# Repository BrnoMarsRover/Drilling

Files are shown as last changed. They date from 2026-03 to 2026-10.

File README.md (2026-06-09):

# Drilling
Repo for Deep Sampling Sub-Task
Release 2025 was mostly a success and allowed us to identify its shortcomings.
Currently working on an overhauled design for ERC 2026.

## Authors

- **Filip Slima** *(Leader)*  
  Responsible for mechanical construction, linear motion system.

- **Vilem Strachon**  
  Responsible for the weighing and storing.

- **Ondrej Stafa**  
  Responsible for DC motor control.

## ESP software structure
```mermaid
graph TD;
    Main-->RoverComm;
    Main-->DeepSampler;
      DeepSampler-->DrillController;
        DrillController-->LinearAxis;
          LinearAxis-->Stepper1;
          LinearAxis-->Encoder1;
          LinearAxis-->LimitSwitch;
          LinearAxis-->CurrentSensor;
        DrillController-->SpiralMotor;
      	DrillController-->HeightSensor;
      DeepSampler-->DeepSampleHolder;
        DeepSampleHolder-->ADC1
        DeepSampleHolder-->StoragePositioner
          StoragePositioner-->Stepper2;
          StoragePositioner-->Encoder2;
  Main-->SurfaceSampleHolder;
    SurfaceSampleHolder-->ADC2
    SurfaceSampleHolder-->Servo1;
    SurfaceSampleHolder-->Servo2;
```

## Communication protocol
[Here](communicationProtocol.md)

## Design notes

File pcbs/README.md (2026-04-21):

# Součástky k nakoupení

- P-MOSFET na MainBoard 2, url: https://cz.mouser.com/ProductDetail/onsemi/FDN338P?qs=HK%252BeIG1iaag%252B6528k3ktAg%3D%3D\&srsltid=AfmBOopaRxGhuw91gWSMGtCGucpT9BQNKklBUyEe4Xwb5UvMYGCLGTto
- ADC rezervní, url: https://cz.mouser.com/ProductDetail/Texas-Instruments/ADS122C04IPWR?qs=7EBvPakHacWatwmmdfjwqQ%3D%3D

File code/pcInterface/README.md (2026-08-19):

# Drilling HMI

A desktop application for controlling and monitoring the drilling device.

It supports two connection modes, switchable in the app:

- **USB Serial** — direct connection to the ESP32 over UART. Used during
  standalone bench testing.
- **UDP (localhost)** — used once the drill is mounted on the rover. This
  app runs alongside the main rover communication app on the same laptop.
  Framed drill messages are sent over a localhost UDP socket to the main
  app, which is responsible for actually getting them to/from the drill
  over the rover link. Responses come back the same way.

## Requirements

- Python 3.8 or newer — download from https://www.python.org/downloads/
  - During installation, tick **"Add Python to PATH"** on the first screen
- For USB Serial mode: the ESP32 connected via USB (USB-to-serial adapter or direct USB)
- For UDP mode: the main rover communication app running on the same machine

## Installation

1. Open CMD and navigate to this folder:
   ```
   cd ...\Drilling\code\pcInterface
   ```

2. Install dependencies:
   ```
   pip install -r requirements.txt
   ```

## Running the application

```
python main.py
```

A window will open with a **Connection** bar at the top.

### USB Serial mode

Select **USB Serial**, choose the correct COM port from the dropdown, and
click **Connect**.

To find the correct COM port: open Device Manager → Ports (COM & LPT) →
look for your USB serial device.

### UDP (localhost) mode

Select **UDP (localhost)** and set two ports:

- **Listen port** — the port this app listens on. The main rover comms
  app must send the drill's responses to `127.0.0.1` on this port.
- **Send port** — the port this app sends to. The main rover comms app
  must be listening on `127.0.0.1` on this port.

These two ports must be different from each other, and must match
whatever the main app is configured to use on its side. Click **Connect**
to open the socket.

Note: UDP mode expects the main rover communication app to already be
running and listening — this app doesn't start or manage it.

The mode switch and its fields lock while connected; disconnect first to
change modes.

## Project structure

```
drilling-hmi/
├── main.py            # Entry point — run this
├── protocol.py        # Message building and parsing (checksum, framing)
├── comm_worker.py      # Background thread handling USB serial and UDP communication
├── gui.py              # All GUI windows and widgets
├── requirements.txt    # Python dependencies
└── README.md            # This file
```

## Notes

- Baud rate is fixed at 38400 as per the protocol spec (USB Serial mode only)
- The application will not send commands if not connected
- The STATE command is sent automatically every 500 ms when connected, regardless of mode
- `serial_worker.py` from earlier versions has been replaced by `comm_worker.py` — delete the old file if it's still present in this folder

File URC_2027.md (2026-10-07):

Feetech STS3215 servo pro pohon závitové tyče nebo nema 14 - potřeba enkoderu\
závitová tyč o měnším průměru\
Cubemars ak45:10 pořád na vrtání\
pořešit jeslit nejde brát 24 nebo 12 pro hlavní motor z roveru - ušetřit váhu měniče

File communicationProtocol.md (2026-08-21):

# Protocol for communication between the drill's microcontroller and rover's master computer

All messages are sent via UART with 38400 baud rate.\
All multi-byte variables are to be sent and received as big-endian - most significant byte is transmitted first.

1. The rover initiates communication by sending a message in the specified format. The payload of the message consists of a code of the function to be executed by the drill. The code is of type uint8. In some cases, the code must be followed by an argument. This is usually a numeric value, for example the desired depth to be drilled.

2. If the drill is able to start performing the function, it sends the function code back. If it is unable to perform the function, it sends back a zero. If further answer is expected (for example the weight of a sample), the function code is followed by the requested value.

## Message format
|Byte number  |Content |
|- |-|
|1 |0x02 |
|2 |Payload length  |
|3...n-2 |Payload  |
|n-1 |Checksum |
|n |0x03 |

The chekcsum algorithm is "Sum complement". See: https://en.wikipedia.org/wiki/Checksum#Sum_complement
The checksum is computed only from the payload.

## Communication program
A program has been developed for communicating with the drill according to this protocol. The program supports two modes of communication
1. The drill can be connected directly to a computer running the program via USB. This is simpler and meant for testing purposes when the drill is not mounted on the rover.
2. When the drill is mounted and connected to the rover, direct USB communication with a PC is not possible. A broader, main program exists for wireless communication with the rover. Our drill communication program then runs on the same computer as the main program. These two programs communicate via UDP localhost. The main program and the rover's computer then act as middlemen between this app and the drill itself. The drill program should send messages to port 5610 and can receive the drill's responses on port 5611.

## Example 1
Rover: 0x02 (start) -> 0x01 (length 1) -> 0x01 (message - reset) -> 0x?? (checksum) -> 0x03 (end)\
Drill: 0x02 (start) -> 0x01 (length 1) -> 0x01 (message - request to reset received. Resetting.) -> 0x?? (checksum) -> 0x03 (end) 

## Example 2
Rover: 0x02 (start) -> 0x01 (length 1) -> 0x42 (GET WEIGHT DEEP) -> 0x?? (checksum) -> 0x03 (end)\
Drill: 0x02 (start) -> 0x01 (length 5) -> 0x42 (Weight request received. Weight follows.) -> 4 bytes-float -> 0x?? (checksum) -> 0x03 (end)

## Function list
| Name and description | Message from rover | Function argument from rover | Response data from drill |
|- |- |- |- |
| RESTART - Restarts the microcontroller. Retracts the deep sample box. Returns the vertical drive to its uppermost position. Also calibrates the vertical position value. | 0x01 | None | None |
| STATE - Requests the state of the drilling mechanism | 0x02 | None | Response is in table below |
| CALIBRATE CARRIAGE DEPTH - Moves the carriage up, until it hits the top limit switch. Sets depth = 0 at that position. | 0x03 | None | None |
| START DEVICE CHECK - Checks whether peripheral devices are connected and responding. | 0x04 | None | None |
| GET DEVICE STATUS - Requests the result of the START DEVICE CHECK | 0x05 | None | uint16 (String of bits. Each bit corresponds to one peripheral device. 1 = OK, 0 = not OK. Order of devices in table below) |
| DRILL SPEED - sets the speed of the drill/spiral | 0x20 | int16 [RPM] | None |
| VERTICAL SPEED - sets the speed of the vertical drive | 0x21 | int8 [0,1 mm/s]<br>e.g.&nbsp;100 = 10mm/s | None |
| STORAGE POSITION - sets the position of the deep sample storage box | 0x22 | uint8 [position] | None |
| MEASURE HEIGHT ABOVE GROUND - requests height measurement. | 0x23 | None | None |
| GET HEIGHT ABOVE GROUND - requests the value of the last height measurement. | 0x24 | None | uint16 [mm] |
| WEIGH DEEP - Start weighing the deep sample. | 0x40 | None | None |
| WEIGH SURFACE - Start weighing the surface sample. | 0x41 | None | None |
| GET WEIGHT DEEP - Requests the result of WEIGH DEEP. | 0x42 | None | float [grams], uint32 [raw ADC value] |
| GET WEIGHT SURFACE - Requests the result of WEIGH SURFACE. | 0x43 | None | float [grams], uint32 [raw ADC value] |
| CALIBRATE 0 DEEP - Starts the calibration procedure. Calibrates the ADC value for empty storage. Needs to be followed by CALIBRATE X DEEP for successful calibration. | 0x44 | None | None |
| CALIBRATE X DEEP - Calibrates the ADC value for X grams in storage. Finishes calibration and saves data to nonvolatile flash memory. | 0x45 | Weight of the object put into storage -  float [grams] | None |
| CALIBRATE 0 SURFACE - Same as above, but for surface sample. | 0x46 | None | None |
| CALIBRATE X SURFACE - Same as above, but for surface sample. | 0x47 | Weight of the object put into storage -  float [grams] | None |
| ROCK OPEN - opens the rock sample box | 0x50 | None | None |
| ROCK CLOSE - closes the rock sample box | 0x51 | None | None |
| SAND OPEN - opens the sand sample box  | 0x52 | None | None |
| SAND CLOSE - closes the sand sample box  | 0x53 | None | None |
| SET HOLD MODE - sets hold mode on the deep storage - locks it in place, but continuously draws current. | 0x54 | None | None |
| CLEAR HOLD MODE - clears hold mode on the deep storage. | 0x55 | None | None |
| STOP AUTO - Stops all automatic procedures. Unlocks manual commands. | 0x60 | None | None |
| DRILL AUTO - Automatically extract, store and weigh a deep sample from specified depth. Blocks manual commands. | 0x61 | Desired drill depth - uint8 [cm] | None |
| STORE AUTO - Automatically store and weigh a sample that is already in the spiral. Blocks manual commands. | 0x62 | None | None |

## STATE response table
| Variable meaning | Data type | Unit |
|- |- |- |
| Carriage depth - current distance of the carriage from uppermost position.<br>It is possible to calculate other distances:<br>Depth under surface = CarriageDepth + carriageTopToSpiralTipMM - linAxisZeroToSensorMM - heightAboveGround (the sensor value).<br>Depth under rover = CarriageDepth + carriageTopToSpiralTipMM - linAxisZeroToSensorMM<br>Where carriageTopToSpiralTipMM = 720<br>linAxisZeroToSensorMM = 775 | int16 | mm |
| Vertical drive speed | int8 | 0,1 mm/s (10 = 1 mm/s) |
| Vertical drive stepper current | uint8 | 0,01 A (100 = 1 A) |
| Spiral motor speed | int16 | RPM |
| Spiral motor winding current | int16 | 0,01 A (100 = 1 A) |
| Spiral motor current draw | int16 | 0,01 A (100 = 1 A) |
| Spiral motor torque | int16 | 0,01 Nm (100 = 1 Nm) |
| Spiral motor temperature | uint8 | °C |
| Deep sample storage angle | uint16 | ° |
| DeepSampler state | uint8 | Code of the state of the autonomous state machine of DeepSampler - meaning in table below. |
| DrillController state | uint8 | Meaning in table below. |
| DeepSampleHolder state | uint8 | Meaning in table below. |

DeepSampler state codes 
| Code | Meaning |
|- |- |
| 0x00 | MANUAL |
| 0x01 | WAITING_FOR_STORAGE_CLEAR |
| 0x02 | DRILLING |
| 0x03 | MOVE_CARRIAGE_TO_STORE |
| 0x04 | MOVING_CARRIAGE_TO_STORE |
| 0x05 | MOVING_STORAGE |
| 0x06 | STORING |
| 0x07 | WEIGHING |
| 0x08 | MOVING_UP |
| 0xFE | DONE |
| 0xFF | ERROR |

## DrillController state codes
| Code | Meaning |
|- |- |
| 0x00 | MANUAL |
| 0x01 | WAITING_FOR_HEIGHT |
| 0x02 | MOVING_DOWN |
| 0x03 | DRILLING |
| 0xFE | DONE |
| 0xFF | ERROR |

## DeepSampleHolder state codes
| Code | Meaning |
|- |- |
| 0x00 | MANUAL |
| 0x01 | STORAGE_MOVING |
| 0x02 | WAITING_FOR_SETTLE |
| 0x03 | WEIGHING |
| 0xFE | DONE |
| 0xFF | ERROR |

## CHECK DEVICES response order
| Order | Device |
| - | - |
| least significant bit - 0 | Vertical drive stepper driver |
| 1 | Vertical drive encoder |
| 2 | Vertical drive current sensor |
| 3 | Spiral motor |
| 4 | Height sensor |
| 5 | Deep sample storage stepper driver |
| 6 | Deep sample storage encoder |
| 7 | Deep sample ADC |
| 8 | Surface sample ADC |

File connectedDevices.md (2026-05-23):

List of devices connected to the drill's microcontroller:

|Device |Means of communication |Bus address / GPIO pin |Communication voltage |Power voltage |
|--- |--- |---|---|---|
|Rover's master computer |UART via USB port on devkit |pins 1, 3 |5 V, through USB converter |x |
|DC motor AK45-10 |UART |pins 16, 17 |3,3 V |24 V  |
|Vertical drive stepper driver (5160)  |SPI | |3,3 V |24 V  |
|Vertical drive stepper encoder |I2C |Programmable I2C address 0x42 |3,3 V |3,3 V |
|Vertical drive limit sensor 2x |+V/GND to GPIO pin | |3,3 V |3,3 V |
|Deep storage stepper driver (2209) |Single Wire UART | |3,3 V |24 V  |
|Deep storage stepper encoder |I2C |Programmable I2C address 0x41 |3,3 V |3,3 V |
|Deep storage ADC + surface storage ADC |I2C |Programmable I2C addresses 0x44,0x45 |3,3 V |3,3 V power, 5 V analog reference |
|Surface storage servo 2x | PWM | | | 5 V | 
|Height sensor |I2C (possible analog and PWM) |Programmable I2C address 0x52 |3,3 V |3,3 V |
|Current sensor |I2C |Programmable I2C address 0x40|3,3 V |24 V |

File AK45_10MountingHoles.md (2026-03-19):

All mounting holes are threaded M2,5.

Side  |  Number  |  Depth [mm]  |
------|----------|--------------|
Top   |         5|             6| 
Bottom|         3|             8|
Flange|         3|             4|

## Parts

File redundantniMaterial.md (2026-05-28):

# Redundantní materiál

články řetězu 

JST PH - nakrimpovaný 3-pin na komunikaci BLDC motoru

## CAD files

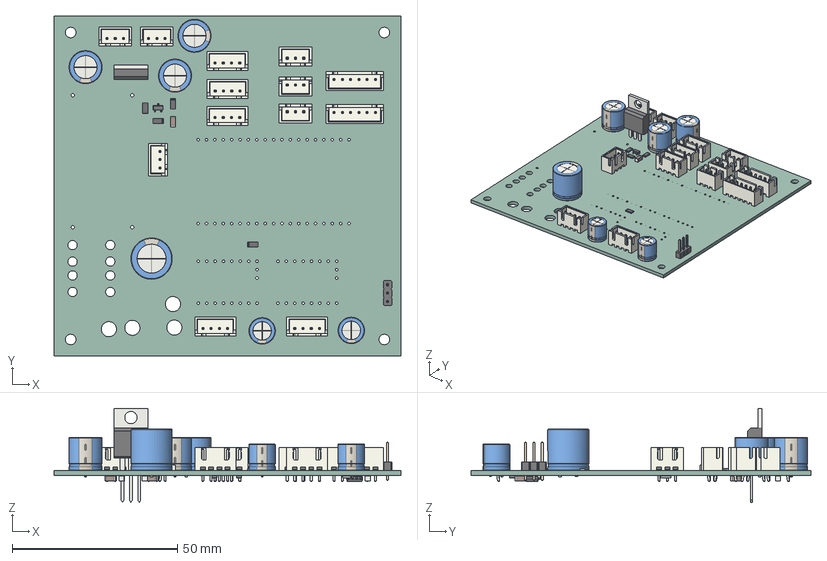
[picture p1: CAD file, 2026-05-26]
pcbs/drill_pcb_v2_DO_NOT_EDIT/PCB.step
105.0 x 103.0 x 28.5 mm
JST_XH_B3B-XH-A_1x03_P2.50mm_Vertical x 6
R_1206_3216Metric x 7
CP_Radial_D8.0mm_P3.50mm x 2
CP_Radial_D10.0mm_P5.00mm x 3
JST_XH_B6B-XH-A_1x06_P2.50mm_Vertical x 2
JST_XH_B4B-XH-A_1x04_P2.50mm_Vertical x 5
CP_Radial_D12.5mm_P5.00mm
TO-220-3_Vertical
C_1206_3216Metric x 6
PinHeader_1x03_P2.54mm_Vertical
SOT-23-3
SOIC-8_3.9x4.9mm_P1.27mm
drill_pcb_PCB

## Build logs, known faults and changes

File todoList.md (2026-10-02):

# TODO list

## Hardware
Krytka spodního ložiska\
Adaptace surface sample boxu pro vysypání\
Design a testování lopatky 2.0 (surface sample)\
Nový Adc board s pinem pro stínění kabelu?\
Silnější motor\
Lepší držení podpěry zásobníku - zbavit se těch krátkých profilů\
Zjednodušit kabeláž\
Nechat si vyrobit nový vrták\
Voděodolnost\
Stínění kabelů

## Software
Úprava rate of penetration  v závislosti na hloubce\
Brát v úvahu proud vertikálního krokáče\
Ať každá I2C komunikace ať jde přes prostředníka (fnc)\
Možnost vypnout koncáky?\
Samovypnutí při timeoutu komunikace\
Sloučit measure + get\
Lepší zobrazení vytížení motoru, průběhu vrtu\
Přidat timeout\
Přidat možnost ignorovat koncáky\
Nějak vyřešit potřebu časté kalibrace\

## Misc
Dopisovat do seznamu materiál co chceme mít redundantní.\
Budoucí testování váhového senzoru nutné s šumem v kastli roveru -> návrh lepšího stínění

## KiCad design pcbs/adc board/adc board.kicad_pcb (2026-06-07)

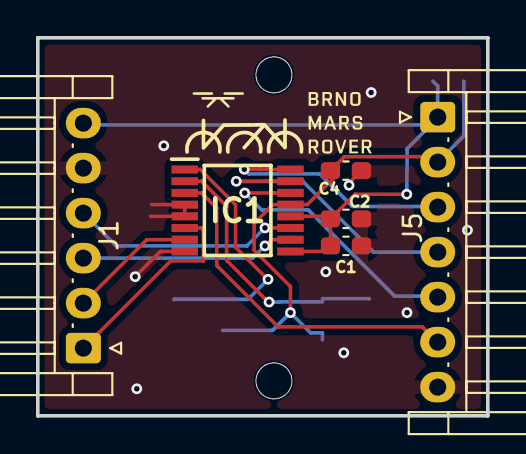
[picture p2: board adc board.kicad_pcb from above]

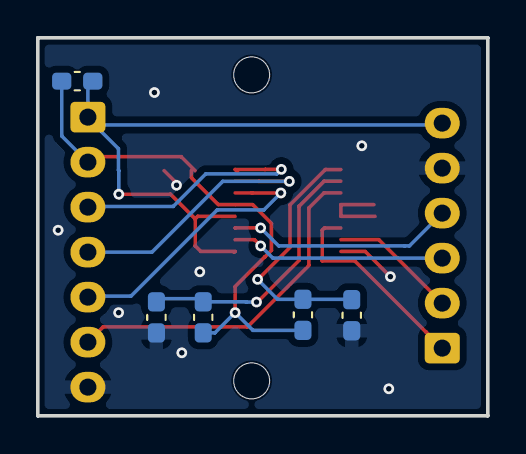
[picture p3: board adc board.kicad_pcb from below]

Board: 2 copper layers, 25.0 x 21.0 mm, 11 parts (5 on the bottom side), 13 nets.

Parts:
C1, C2, C4: C; C_0603_1608Metric_Pad1.08x0.95mm_HandSolder
IC1: ADS122C04IPWR; SOP65P640X120-16N
J1: Screw_Terminal_01x06; JST_EH_S6B-EH_1x06_P2.50mm_Horizontal
J5: Screw_Terminal_01x07; JST_EH_S7B-EH_1x07_P2.50mm_Horizontal
solderable_connection0, solderable_connection1, solderable_connection2, solderable_connection3, solderable_connection4: C; C_0603_1608Metric_Pad1.08x0.95mm_HandSolder

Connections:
+3.3V: C4.2, IC1.13 (DVDD), J5.2, solderable_connection0.1, solderable_connection2.1, solderable_connection3.1
+5V: C1.1, C2.1, IC1.9 (REFP), IC1.12 (AVDD), J1.6, J5.1, solderable_connection0.2
AIN0: IC1.11 (AIN0), J1.4
AIN1: IC1.10 (AIN1), J1.3
AIN2: IC1.7 (AIN2), J1.2
AIN3: IC1.6 (AIN3), J1.1
GND: C1.2, C2.2, C4.1, IC1.4 (DGND), IC1.5 (AVSS), IC1.8 (REFN), J1.5, J5.7, solderable_connection1.1, solderable_connection4.1
unnamed: IC1.1 (A0), solderable_connection3.2, solderable_connection4.2
unnamed: IC1.2 (A1), solderable_connection1.2, solderable_connection2.2
SCL: IC1.16 (SCL), J5.3
SDA: IC1.15 (SDA), J5.4
neg_DRDY: IC1.14 (~DRDY), J5.5
neg_RESET: IC1.3 (~RESET), J5.6

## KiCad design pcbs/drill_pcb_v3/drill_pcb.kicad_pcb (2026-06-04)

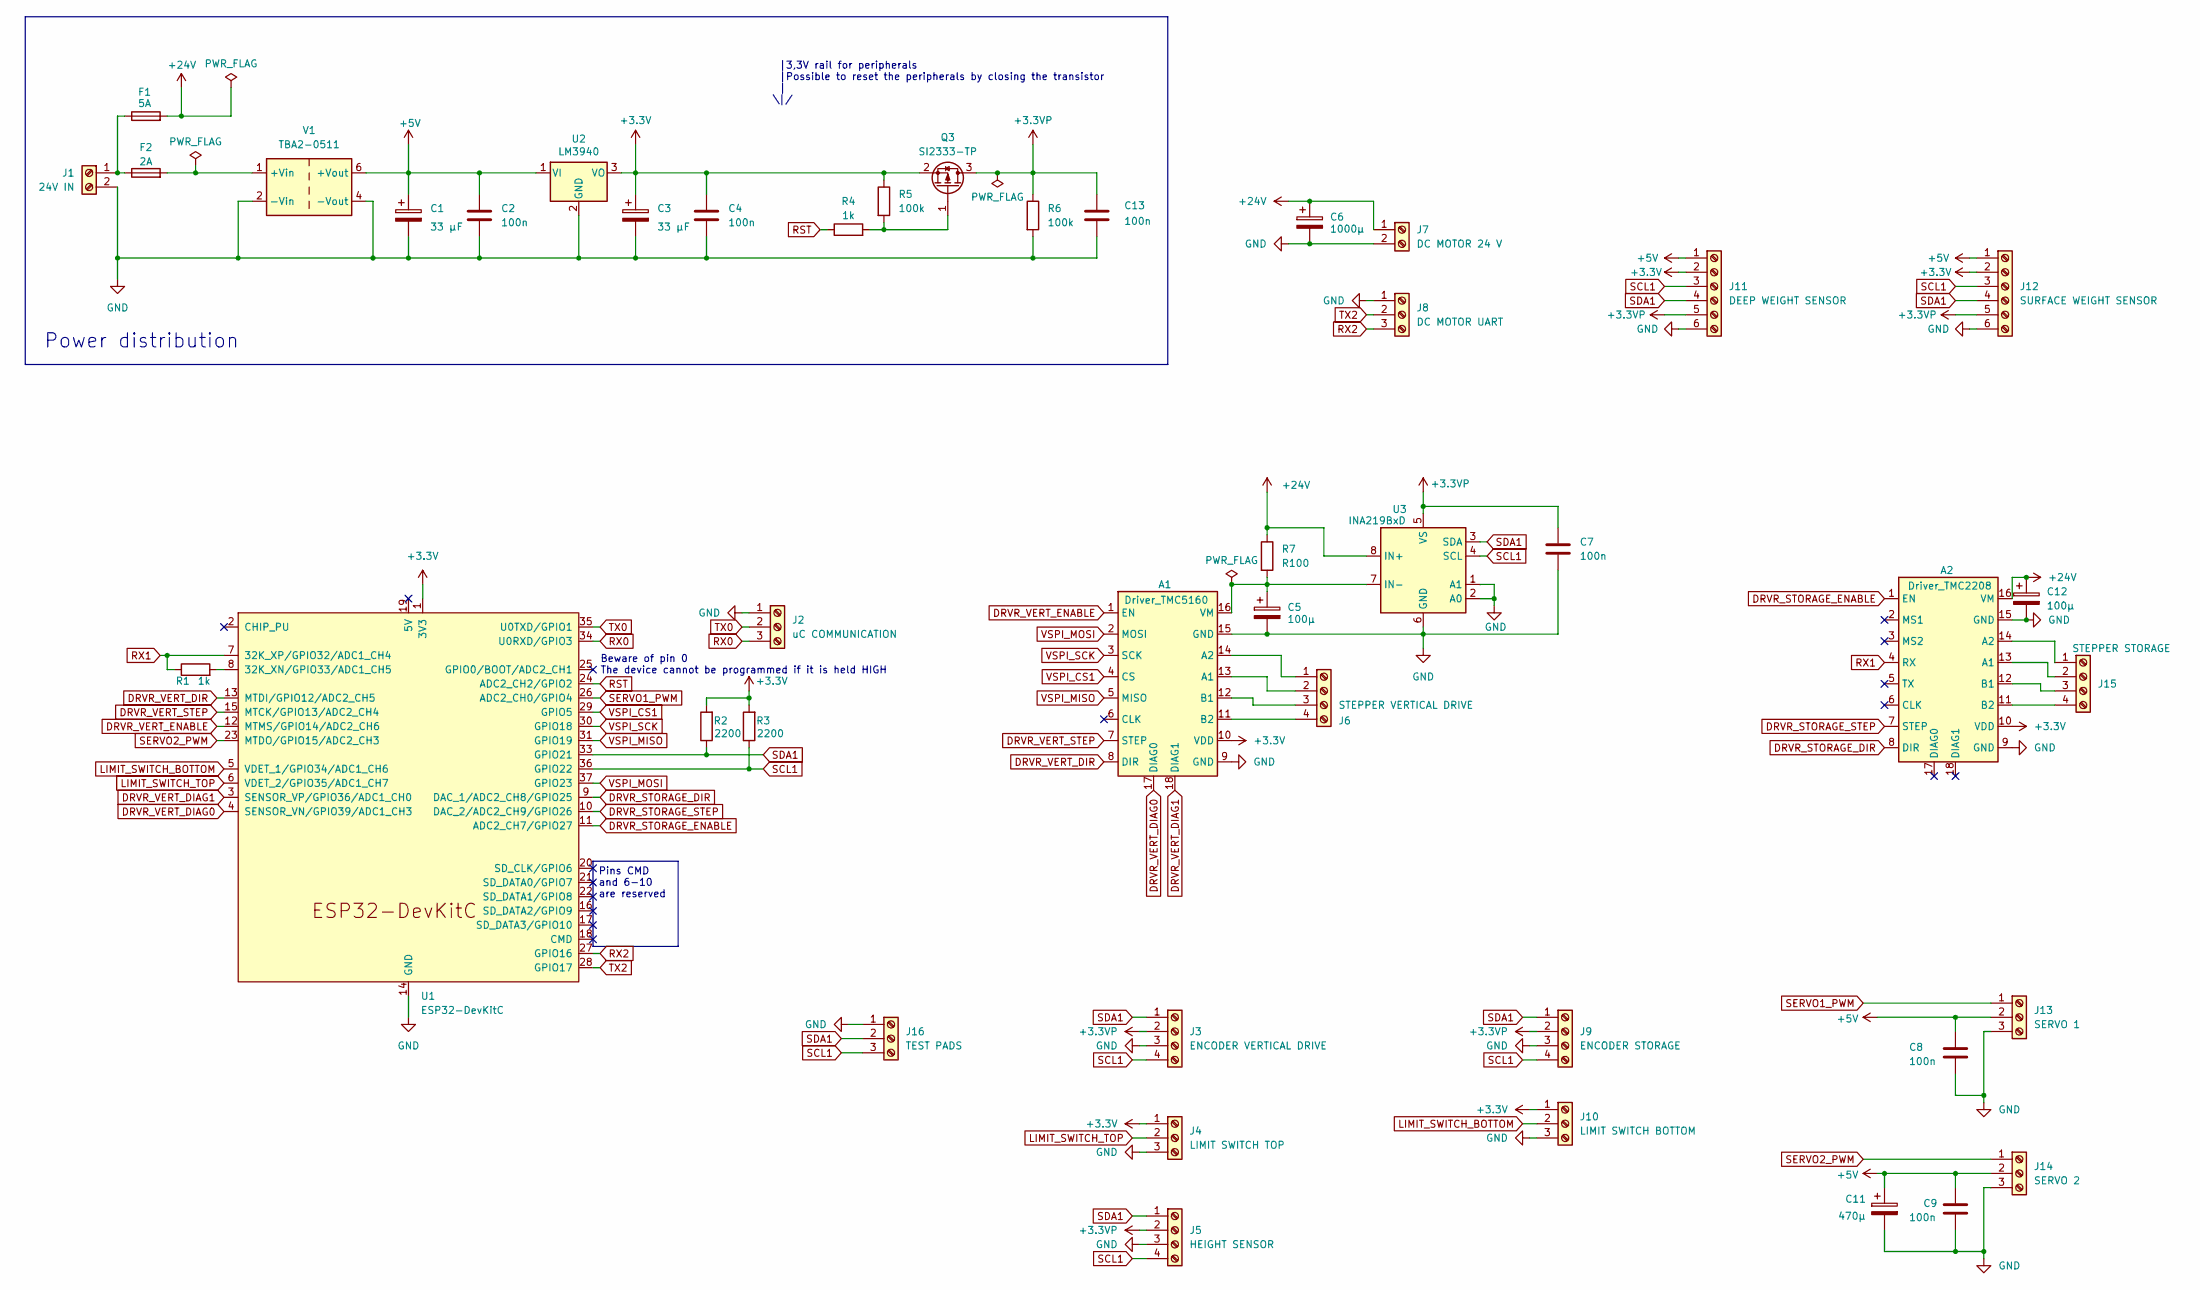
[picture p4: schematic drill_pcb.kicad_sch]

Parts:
A1: Driver_TMC5160
A2: Driver_TMC2208
C1, C3: 33 μF; CP_Radial_D10.0mm_P5.00mm
C2, C4, C7, C8, C9, C13: 100n; C_1206_3216Metric_Pad1.33x1.80mm_HandSolder
C5, C12: 100μ; CP_Radial_D8.0mm_P3.50mm
C6: 1000μ; CP_Radial_D12.5mm_P5.00mm
C11: 470μ; CP_Radial_D10.0mm_P5.00mm
F1: 5A; AUTOFUSE_HOLDER
F2: 2A; AUTOFUSE_HOLDER
J1: 24V IN; DEANS
J2: uC COMMUNICATION; JST_XH_B3B-XH-A_1x03_P2.50mm_Vertical
J3: ENCODER VERTICAL DRIVE; JST_XH_B4B-XH-A_1x04_P2.50mm_Vertical
J4: LIMIT SWITCH TOP; JST_XH_B3B-XH-A_1x03_P2.50mm_Vertical
J5: HEIGHT SENSOR; JST_XH_B4B-XH-A_1x04_P2.50mm_Vertical
J6: STEPPER VERTICAL DRIVE; JST_XH_B4B-XH-A_1x04_P2.50mm_Vertical
J7: DC MOTOR 24 V; DEANS
J8: DC MOTOR UART; JST_XH_B3B-XH-A_1x03_P2.50mm_Vertical
J9: ENCODER STORAGE; JST_XH_B4B-XH-A_1x04_P2.50mm_Vertical
J10: LIMIT SWITCH BOTTOM; JST_XH_B3B-XH-A_1x03_P2.50mm_Vertical
J11: DEEP WEIGHT SENSOR; JST_XH_B6B-XH-A_1x06_P2.50mm_Vertical
J12: SURFACE WEIGHT SENSOR; JST_XH_B6B-XH-A_1x06_P2.50mm_Vertical
J13: SERVO 1; JST_XH_B3B-XH-A_1x03_P2.50mm_Vertical
J14: SERVO 2; JST_XH_B3B-XH-A_1x03_P2.50mm_Vertical
J15: STEPPER STORAGE; JST_XH_B4B-XH-A_1x04_P2.50mm_Vertical
J16: TEST PADS; PinHeader_1x03_P2.54mm_Vertical
Q3: SI2333-TP; SOT-23-3
R1, R4: 1k; R_1206_3216Metric
R2, R3: 2200; R_1206_3216Metric
R5, R6: 100k; R_1206_3216Metric
R7: R100; R_1206_3216Metric
U1: ESP32-DevKitC
U2: LM3940; TO-220-3_Vertical
U3: INA219BxD; SOIC-8_3.9x4.9mm_P1.27mm
V1: TBA2-0511; dcdc_menic

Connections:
+3.3V: A1.10 (VDD), A2.10 (VDD), C3.1, C4.1, J4.1, J10.1, J11.2, J12.2, Q3.2 (S), R2.2, R3.2, R5.1, U1.1 (3V3), U2.3 (VO)
+5V: C1.1, C2.1, C8.1, C9.1, C11.1, J11.1, J12.1, J13.2, J14.2, U2.1 (VI), V1.6 (+Vout)
+24V: A2.16 (VM), C6.1, C12.1, F1.2, J7.1, R7.1, U3.8 (IN+)
DRVR_STORAGE_DIR: A2.8 (DIR), U1.9 (DAC_1/ADC2_CH8/GPIO25)
DRVR_STORAGE_ENABLE: A2.1 (EN), U1.11 (ADC2_CH7/GPIO27)
DRVR_STORAGE_STEP: A2.7 (STEP), U1.10 (DAC_2/ADC2_CH9/GPIO26)
DRVR_VERT_DIAG0: A1.17 (DIAG0), U1.4 (SENSOR_VN/GPIO39/ADC1_CH3)
DRVR_VERT_DIAG1: A1.18 (DIAG1), U1.3 (SENSOR_VP/GPIO36/ADC1_CH0)
DRVR_VERT_DIR: A1.8 (DIR), U1.13 (MTDI/GPIO12/ADC2_CH5)
DRVR_VERT_ENABLE: A1.1 (EN), U1.12 (MTMS/GPIO14/ADC2_CH6)
DRVR_VERT_STEP: A1.7 (STEP), U1.15 (MTCK/GPIO13/ADC2_CH4)
GND: A1.9 (GND), A1.15 (GND), A2.9 (GND), A2.15 (GND), C1.2, C2.2, C3.2, C4.2, C5.2, C6.2, C7.2, C8.2, C9.2, C11.2, C12.2, C13.2, J1.2, J2.1, J3.3, J4.3, J5.3, J7.2, J8.1, J9.3, J10.3, J11.6, J12.6, J13.3, J14.3, J16.1, R6.2, U1.14 (GND), U1.32 (GND), U1.38 (GND), U2.2 (GND), U3.1 (A1), U3.2 (A0), U3.6 (GND), V1.2 (-Vin), V1.4 (-Vout)
LIMIT_SWITCH_BOTTOM: J10.2, U1.5 (VDET_1/GPIO34/ADC1_CH6)
LIMIT_SWITCH_TOP: J4.2, U1.6 (VDET_2/GPIO35/ADC1_CH7)
unnamed: A1.13 (A1), J6.2
unnamed: A1.14 (A2), J6.1
unnamed: A1.12 (B1), J6.3
unnamed: A1.11 (B2), J6.4
unnamed: A1.16 (VM), C5.1, R7.2, U3.7 (IN-)
unnamed: A2.13 (A1), J15.2
unnamed: A2.14 (A2), J15.1
unnamed: A2.12 (B1), J15.3
unnamed: A2.11 (B2), J15.4
unnamed: F1.1, F2.1, J1.1
unnamed: Q3.1 (G), R4.2, R5.2
unnamed: R1.2, U1.8 (32K_XN/GPIO33/ADC1_CH5)
unnamed: F2.2, V1.1 (+Vin)
RX0: J2.3, U1.34 (U0RXD/GPIO3)
RX1: A2.4 (RX), R1.1, U1.7 (32K_XP/GPIO32/ADC1_CH4)
RX2: J8.3, U1.27 (GPIO16)
SCL1: J3.4, J5.4, J9.4, J11.3, J12.3, J16.3, R3.1, U1.36 (GPIO22), U3.4 (SCL)
SDA1: J3.1, J5.1, J9.1, J11.4, J12.4, J16.2, R2.1, U1.33 (GPIO21), U3.3 (SDA)
SERVO1_PWM: J13.1, U1.26 (ADC2_CH0/GPIO4)
SERVO2_PWM: J14.1, U1.23 (MTDO/GPIO15/ADC2_CH3)
TX0: J2.2, U1.35 (U0TXD/GPIO1)
TX2: J8.2, U1.28 (GPIO17)
VSPI_CS1: A1.4 (CS), U1.29 (GPIO5)
VSPI_MISO: A1.5 (MISO), U1.31 (GPIO19)
VSPI_MOSI: A1.2 (MOSI), U1.37 (GPIO23)
VSPI_SCK: A1.3 (SCK), U1.30 (GPIO18)

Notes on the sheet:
Beware of pin 0 The device cannot be programmed if it is held HIGH
Power distribution
|3,3V rail for peripherals |Possible to reset the peripherals by closing the transistor | \|/
Pins CMD and 6-10 are reserved

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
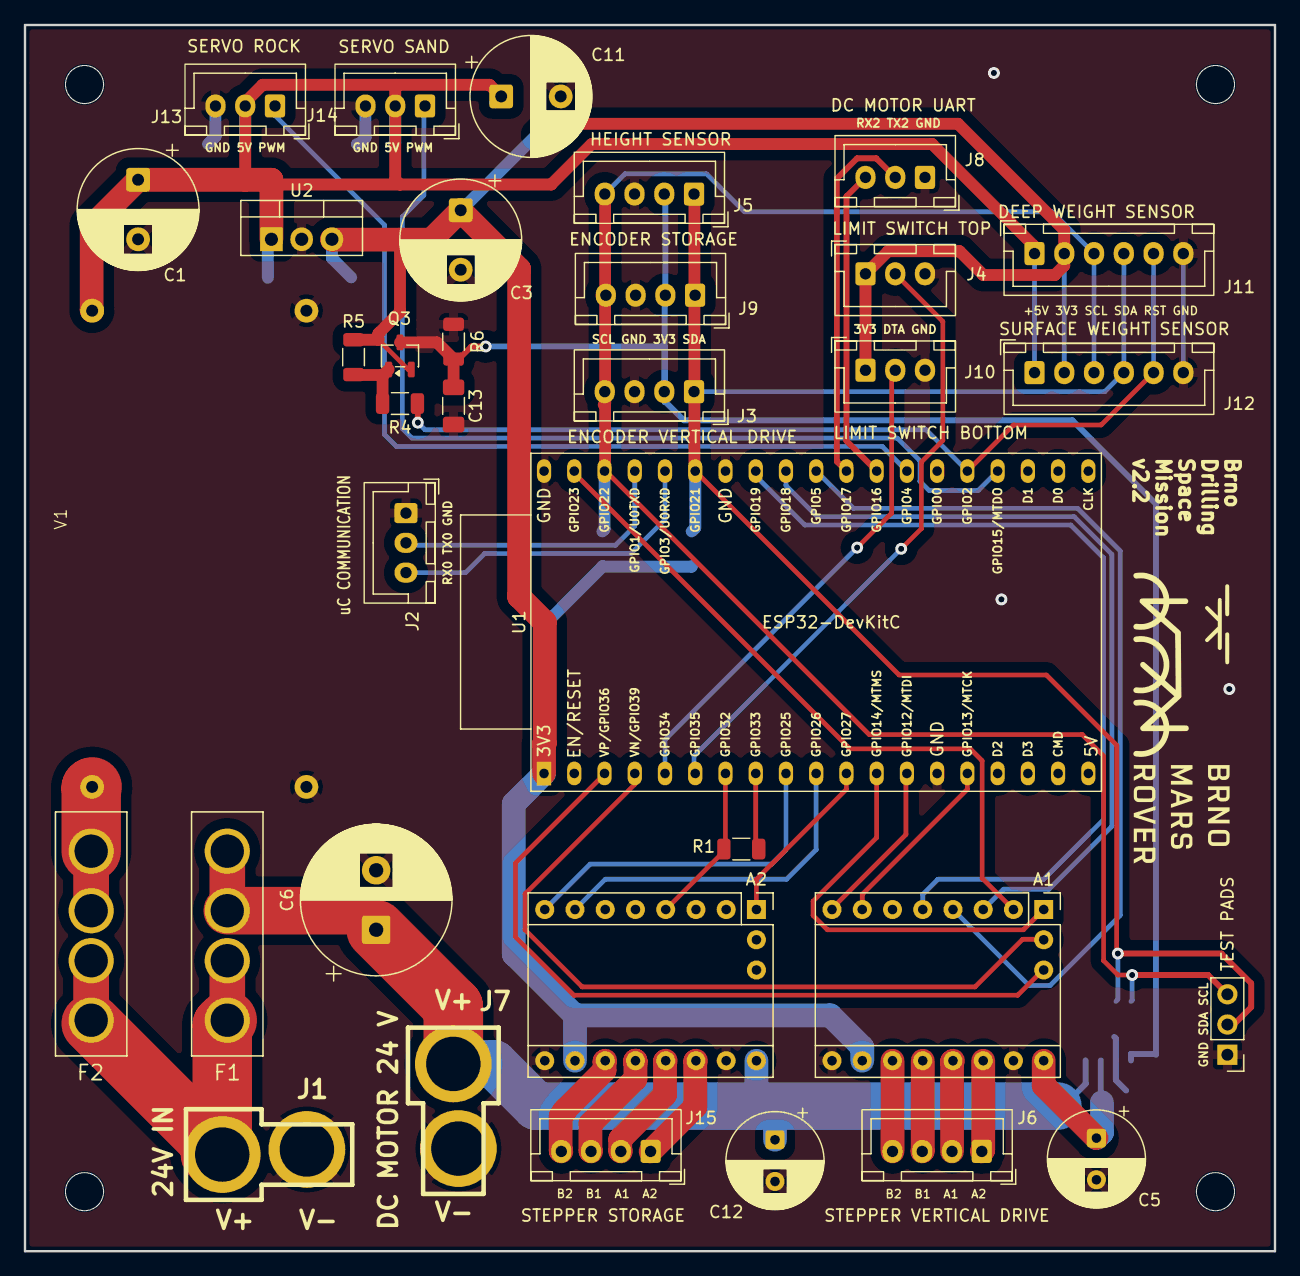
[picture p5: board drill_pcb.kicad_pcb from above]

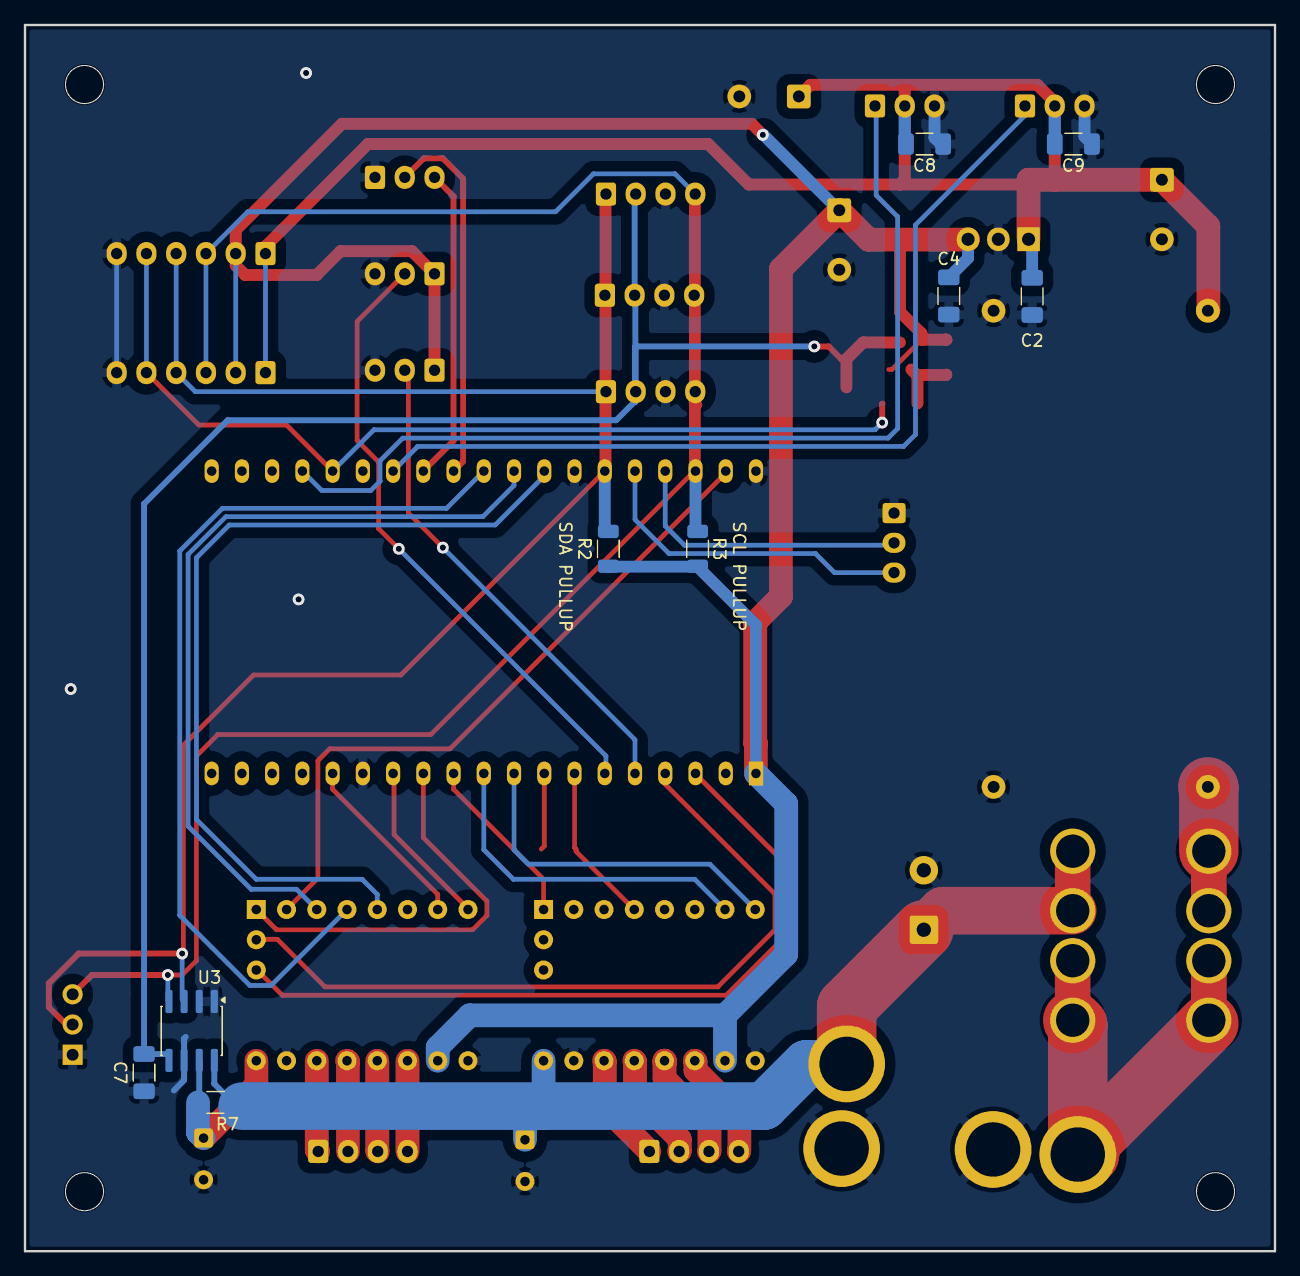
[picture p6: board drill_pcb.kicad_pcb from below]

Board: 2 copper layers, 105.0 x 103.0 mm, 44 parts (9 on the bottom side), 42 nets.

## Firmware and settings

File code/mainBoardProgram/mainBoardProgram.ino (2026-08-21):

#include <Arduino.h>
#include <HardwareSerial.h>
#include <Wire.h>

#include "src/RoverComm/RoverComm.h"
#include "src/DeepSampler/DeepSampler.h"
#include "src/SurfaceSampleHolder/SurfaceSampleHolder.h"


//-------I2C
constexpr uint8_t sdaPin = 21;
constexpr uint8_t sclPin = 22;
constexpr uint32_t i2cFrequency = 100000;
TwoWire I2CBus(0);

HardwareSerial& roverSerial = Serial0;

void setupI2CBus()
{
  // Print starting message for I2C recovery and setup
  roverSerial.println(F("Starting I2C Bus Recovery and Setup..."));

  // Check if I2C bus is free
  if (isI2CBusFree())
  {
    roverSerial.println(F("I2C bus is already free."));
  } else
  {
    // Bus is stuck, attempt recovery
    roverSerial.println(F("I2C bus is stuck, attempting recovery..."));
    if (i2cRecoverBus())
    {
      roverSerial.println(F("I2C bus recovery successful."));
    } else
    {
      roverSerial.println(F("I2C bus recovery failed!"));
    }
  }

  // Initialize the I2C bus
  I2CBus.begin(sdaPin, sclPin, i2cFrequency);
  I2CBus.setTimeOut(50);

  roverSerial.println(F("I2C Bus Setup Complete."));
}

bool isI2CBusFree()
{
  // Check if the SDA and SCL lines are both high (idle state for I2C)
  return (digitalRead(sdaPin) == HIGH && digitalRead(sclPin) == HIGH);
}

bool i2cRecoverBus()
{
  pinMode(sdaPin, INPUT_PULLUP);
  pinMode(sclPin, INPUT_PULLUP);

  if (digitalRead(sdaPin) == HIGH && digitalRead(sclPin) == HIGH)
  {
    return true; // Bus is already free
  }

  roverSerial.println(F("Attempting I2C bus recovery..."));

  // Try to generate clock pulses on SCL to free the bus
  pinMode(sclPin, OUTPUT_OPEN_DRAIN);
  pinMode(sdaPin, INPUT_PULLUP);

  for (int i = 0; i < 20; i++)
  {  // Try up to 20 clock pulses
    digitalWrite(sclPin, LOW);
    delayMicroseconds(10);
    digitalWrite(sclPin, HIGH);
    delayMicroseconds(10);

    if (digitalRead(sdaPin) == HIGH)
    {
      roverSerial.println(F("SDA line released. Bus is free."));
      return true; // SDA line released, bus is free
    }
  }

  // Send STOP condition to release the bus
  pinMode(sdaPin, OUTPUT_OPEN_DRAIN);
  digitalWrite(sdaPin, LOW);
  delayMicroseconds(10);
  digitalWrite(sclPin, HIGH);
  delayMicroseconds(10);
  digitalWrite(sdaPin, HIGH);
  delayMicroseconds(10);

  pinMode(sdaPin, INPUT_PULLUP);
  pinMode(sclPin, INPUT_PULLUP);

  bool success = (digitalRead(sdaPin) == HIGH);
  roverSerial.println(success ? F("I2C recovery successful.") : F("I2C recovery failed."));

  return success;
}

//---------PERIPHERAL CLASSES
DeepSampler deepSampler(I2CBus, roverSerial);
SurfaceSampleHolder surfaceSampleHolder(I2CBus, roverSerial);

RoverComm roverComm(roverSerial);

void respondToMsg(const RoverMessage& msg)
{
  switch(msg.getCommandCode())
  {
    case CMD_RESTART:
    {
      roverComm.sendAck(CMD_RESTART);
      ESP.restart();
      break;
    }

    case CMD_STATE:
    {
      roverComm.sendState(
        deepSampler.getCarriageDepthMM(),
        deepSampler.getCarriageSpeedMMps(),
        deepSampler.getVerticalStepperCurrentA(),
        deepSampler.getSpiralMotorData(),
        deepSampler.storageGetCurrentAngle(),  //deep sample storage angle
        deepSampler.getAutoState(),
        deepSampler.getDrillControllerState(),
        deepSampler.getDeepSampleHolderState()
      );
      break;
    }

    case CMD_CALIBRATE_CARRIAGE_DEPTH:
    {
      if(deepSampler.setCarriageSpeedMMps(-10.0))
        roverComm.sendAck(CMD_CALIBRATE_CARRIAGE_DEPTH);
      else
        roverComm.sendNack();
      break;
    }

    case CMD_START_DEVICE_CHECK:
    {
      roverComm.sendAck(CMD_START_DEVICE_CHECK);
      break;
    }

    case CMD_GET_DEVICE_STATUS:
    {
      roverComm.sendDeviceStatus(
        deepSampler.verticalStepperConnected(), //vertStepper
        deepSampler.verticalEncoderConnected(), //vertEncoder
        deepSampler.currentSensorIsConnected(),
        deepSampler.spiralMotorConnected(), //spiralMotor
        deepSampler.heightSensorConnected(), //heightSensor
        deepSampler.deepSampleStepperConnected(),  // deepSampleStepper
        deepSampler.deepSampleEncoderConnected(),  // deepSampleEncoder
        deepSampler.getAdcConnected(), //deepSampleADC
        surfaceSampleHolder.getAdcConnected() //surfaceSampleADC
      );
      break;
    }

    case CMD_DRILL_SPEED:
    {
      if(deepSampler.setSpiralRPM(msg.getInt16Arg()))
        roverComm.sendAck(CMD_DRILL_SPEED);
      else
        roverComm.sendNack();
      break;
    }

    case CMD_VERTICAL_SPEED:
    {
      if(deepSampler.setCarriageSpeedMMps(((float)msg.getInt8Arg())*0.1))
        roverComm.sendAck(CMD_VERTICAL_SPEED);
      else
        roverComm.sendNack();
      break;
    }

    case CMD_STORAGE_POSITION:
    {
      if(deepSampler.storageMoveToSlot((StepperPositioner::StoragePosition)msg.getUint8Arg()))
        roverComm.sendAck(CMD_STORAGE_POSITION);
      else
        roverComm.sendNack();
      break;
    }

    case CMD_MEASURE_HEIGHT_ABOVE_GROUND:
    {
      if(deepSampler.startDistFromSurfaceMeasure())
        roverComm.sendAck(CMD_MEASURE_HEIGHT_ABOVE_GROUND);
      else
        roverComm.sendNack();
      break;
    }

    case CMD_GET_HEIGHT_ABOVE_GROUND:
    {
      roverComm.sendUint16(CMD_GET_HEIGHT_ABOVE_GROUND, deepSampler.getDistFromSurfaceMM());
      break;
    }
    
    case CMD_WEIGH_DEEP:
    {
      if(deepSampler.requestMeasure())
        roverComm.sendAck(CMD_WEIGH_DEEP);
      else
        roverComm.sendNack();
      break;
    }

    case CMD_WEIGH_SURFACE:
    {
      if(surfaceSampleHolder.requestMeasure())
        roverComm.sendAck(CMD_WEIGH_SURFACE);
      else
        roverComm.sendNack();
      break;
    }

    case CMD_GET_WEIGHT_DEEP:
    {
      if(deepSampler.getResultReady()){
        roverComm.sendWeight(CMD_GET_WEIGHT_DEEP, deepSampler.getLastWeight());
      }
      else
        roverComm.sendNack();
      break;
    }

    case CMD_GET_WEIGHT_SURFACE:
      if(surfaceSampleHolder.getResultReady()){
        roverComm.sendWeight(CMD_GET_WEIGHT_SURFACE, surfaceSampleHolder.getLastWeight());
      }
      else
        roverComm.sendNack();
      break;

    case CMD_CALIBRATE_0_DEEP:
    {
      if(deepSampler.setCalibration0())
        roverComm.sendAck(CMD_CALIBRATE_0_DEEP);
      else
        roverComm.sendNack();
      break;
    }

    case CMD_CALIBRATE_X_DEEP:
    {
      if(deepSampler.setCalibrationX(msg.getFloatArg())) // getFloat()
        roverComm.sendAck(CMD_CALIBRATE_X_DEEP);
      else
        roverComm.sendNack();
      break;
    }
    
    case CMD_CALIBRATE_0_SURFACE:
    {
      if(surfaceSampleHolder.setCalibration0())
        roverComm.sendAck(CMD_CALIBRATE_0_SURFACE);
      else
        roverComm.sendNack();
      break;
    }
    
    case CMD_CALIBRATE_X_SURFACE:
    {
      if(surfaceSampleHolder.setCalibrationX(msg.getFloatArg())) // getFloat()
        roverComm.sendAck(CMD_CALIBRATE_X_SURFACE);
      else
        roverComm.sendNack();
      break;
    }
    
    case CMD_ROCK_OPEN:
    {
      if(surfaceSampleHolder.openRockBox())
        roverComm.sendAck(CMD_ROCK_OPEN);
      else
        roverComm.sendNack();
      break;
    }

    case CMD_ROCK_CLOSE:
    {
      if(surfaceSampleHolder.closeRockBox())
        roverComm.sendAck(CMD_ROCK_CLOSE);
      else
        roverComm.sendNack();
      break;
    }

    case CMD_SAND_OPEN:
    {
      if(surfaceSampleHolder.openSandBox())
        roverComm.sendAck(CMD_SAND_OPEN);
      else
        roverComm.sendNack();
      break;
    }
    
    case CMD_SAND_CLOSE:
    {
      if(surfaceSampleHolder.closeSandBox())
        roverComm.sendAck(CMD_SAND_CLOSE);
      else
        roverComm.sendNack();
      break;
    }

    case SET_HOLD_MODE:
    {
      if(deepSampler.storageSetHoldMode(true))
      {
        roverComm.sendAck(SET_HOLD_MODE);
      }
      else
      {
        roverComm.sendNack();
      }
      break;
    }

    case CLEAR_HOLD_MODE:
    {
      if(deepSampler.storageSetHoldMode(false))
      {
        roverComm.sendAck(CLEAR_HOLD_MODE);
      }
      else
      {
        roverComm.sendNack();
      }
      break;
    }

    case CMD_STOP_AUTO:
    {
      if(deepSampler.setManualControl())
      {
        roverComm.sendAck(CMD_STOP_AUTO);
      }
      else
      {
        roverComm.sendNack();
      }
      break;
    }

    case CMD_DRILL_AUTO:
    {
      if(deepSampler.autoDrillStoreWeigh(10*((float)msg.getUint8Arg()) ) )
        roverComm.sendAck(CMD_DRILL_AUTO);
      else
        roverComm.sendNack();
      break;
    }
    
    case CMD_STORE_AUTO:
    {
      if(deepSampler.autoStoreWeigh())
        roverComm.sendAck(CMD_STORE_AUTO);
      else
        roverComm.sendNack();

      break;
    }

    default:
    {
      roverComm.sendNack();
      break;
    }
  }
}

// 3,3 V MOSFET switch - RESET pin
constexpr uint8_t resetPin = 2;
void startPeripheralReset()
{
  digitalWrite(resetPin, HIGH);
}
void endPeripheralReset()
{
  digitalWrite(resetPin, LOW);
}
void activeDelayReset()
{
  startPeripheralReset();
  delay(100);
  endPeripheralReset();
  delay(100);
}


void setup()
{
  pinMode(resetPin, OUTPUT);
  activeDelayReset();
  roverSerial.begin(38400);

  setupI2CBus();

  deepSampler.begin();
  surfaceSampleHolder.begin();
}

void loop()
{
  deepSampler.update();

  roverComm.handle();
  while(roverComm.messageAvailable())
  {
    respondToMsg(roverComm.popMessage());
  }
}

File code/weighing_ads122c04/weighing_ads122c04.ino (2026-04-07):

#include "ads122c04_lib.h"
#include <Wire.h>

const int btn_tmp = 4;
const int n_reset = 5;

ADS122C04 adc;          // default address 0x40 (A1=DGND, A0=DGND)

void setup() {
    Serial.begin(9600);
    while (!Serial) delay(10);

    pinMode(SDA, INPUT_PULLUP);
    pinMode(SCL, INPUT_PULLUP);
    pinMode(btn_tmp, INPUT_PULLUP); // erase for ESP
    pinMode(n_reset, OUTPUT);
    digitalWrite(n_reset, HIGH);

    Wire.begin();

    adc.init();
    /*
    // Verify register contents
    Serial.println(F("Register readback:"));
    for(uint8_t i = 0; i < 4; i++){
        Wire.beginTransmission(0x45);
        Wire.write(0x20 | (i << 2));    // RREG command
        Wire.endTransmission(false);
        Wire.requestFrom((uint8_t)0x45, (uint8_t)1);
        uint8_t val = Wire.read();
        Serial.print(F("REG")); Serial.print(i);
        Serial.print(F(" = 0x")); Serial.println(val, HEX);
    }
    Serial.println(F("Expected: 0x0E, 0x08, 0x05, 0x70"));
    */
    // Check chip temperature
    Serial.print(F("Chip temperature: "));
    Serial.print(adc.read_temperature(), 4);
    Serial.println(F(" °C"));
    
    adc.scale_calibrate();
    adc.tare();
    Serial.println(F("Scale ready"));
}

void loop() {
  if(digitalRead(btn_tmp) == LOW){ // erase for ESP
    adc.tare();
  }
  //Serial.println(adc.read());
  //delay(50);
  Serial.print(adc.measure_weight(), 4);
  Serial.println("g");
  delay(1000);
}

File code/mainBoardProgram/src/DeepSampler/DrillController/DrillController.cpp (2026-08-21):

#include "DrillController.h"

// ------------------------------------------------------------------ //
//  Public                                                            //
// ------------------------------------------------------------------ //

DrillController::DrillController(TwoWire& wire, HardwareSerial& debugSerial,  FastAccelStepperEngine& stepperEngine):
  _wire(wire),
  _debugSerial(debugSerial),
   _stepperEngine(stepperEngine),
  // ===== LINEAR AXIS =====
  _linearAxis(
    13, // STEP
    12, // DIR
    14, // EN
    5,  // CS (TMC5160)
    18, // SCK
    19, // MISO
    23, // MOSI
    35, // horní koncák
    34,  // dolní koncák
    wire,  //i2c bus class
    stepperEngine,
    0x42 // adresa AS5600
  ),
  _motorDriver(Serial2, debugSerial, 16, 17),
  _heightSensor(wire)
{
}

bool DrillController::begin()
{
  bool beginOK = true;
  if (!_linearAxis.begin(600, 16)) {
    _debugSerial.println("Linear axis FAILED");
    beginOK = false;
  }
  if (!_heightSensor.begin()) {
    _debugSerial.println("TOF FAILED");
    beginOK = false;
  }
  if(!_motorDriver.begin())
  {
    _debugSerial.println("MOTOR FAILED");
    beginOK = false;
  }

  return beginOK;
}

void DrillController::update()
{
  _linearAxis.update();
  _motorDriver.update();
  _heightSensor.update();


  switch(_autoState)
  {
    case AutoState::MANUAL:
    {
      break;
    }

    case AutoState::WAITING_FOR_HEIGHT:
    {
      if(_heightSensor.dataReady())
      {
        if(_heightSensor.getDistanceMM() < 400.0)
        {
          if(spiralDepthBelowGroundMM() > -20.0)
          {
            if(_motorDriver.setRPM(_targetSpiralRPS*60))
            {
              _autoState = AutoState::DRILLING;
            }
            else
            {
              enterError();
            }
          }
          else
          {
            _autoState = AutoState::MOVING_DOWN;
            _linearAxis.setSpeedMMps(10);
          }
        }
        else
        {
          _heightSensor.startMeasure();
        }
      }

      break;
    }

    case AutoState::MOVING_DOWN:
    {
      if(spiralDepthBelowGroundMM() > -20.0)
      {
        if(_motorDriver.setRPM(_targetSpiralRPS*60))
        {
          _autoState = AutoState::DRILLING;
        }
        else
        {
          enterError();
        }
      }
      break;
    }

    case AutoState::DRILLING:
    {
      if(spiralDepthBelowGroundMM() > _targetDepthMM)
      {
        if(_linearAxis.stop() && _motorDriver.setRPM(0.0))
        {
          _autoState = AutoState::DONE;
        }
        else
        {
          enterError();
        }
      }
      else
      {
        if(!(_linearAxis.setSpeedMMps((_motorDriver.getMotorData().RPM/60)*_rateOfPenetrationMMpRev)))
        {
          enterError();
        }
      }
      break;
    }
    
    case AutoState::DONE:
    {
      break;
    }
    
    case AutoState::ERROR:
    {
      break;
    }
  }
}

bool DrillController::setCarriageSpeedMMps(float MMps)
{
  if (_autoState == AutoState::MANUAL)
  {
    _linearAxis.setSpeedMMps(MMps);
    return true;
  }
  else
    return false;
}

float DrillController::getCarriageSpeedMMps() const { return _linearAxis.getSpeedMMps(); }

float DrillController::getCarriageDepthMM() const { return _linearAxis.getDepthMM(); }

float DrillController::getVerticalStepperCurrentA() const { return _linearAxis.getStepperCurrentA(); }

bool DrillController::currentSensorIsConnected() const {return _linearAxis.currentSensorIsConnected(); }

bool DrillController::isDepthCalibrated() const {return _linearAxis.isDepthCalibrated(); }

bool DrillController::setSpiralRPM(float rpm)
{
  if (_autoState == AutoState::MANUAL)
  {
    return _motorDriver.setRPM(rpm);
  }
  else
    return false;
}

CubeMarsData DrillController::getSpiralMotorData() { return _motorDriver.getMotorData(); }

// Integrated drill control
DrillController::AutoState DrillController::getAutoState() { return _autoState; }

bool DrillController::startDistFromSurfaceMeasure()
{
  return _heightSensor.startMeasure();
}

float DrillController::getDistFromSurfaceMM()
{
  return _heightSensor.getDistanceMM();
}

bool DrillController::setManualControl()
{
  _autoState = AutoState::MANUAL;
  _motorDriver.setRPM(0);
  _linearAxis.setSpeedMMps(0);
  return true;
}

bool DrillController::autoDrillToDepth(float rateOfPenetrationMMpRev, float targetRPM, float targetDepthMM)
{
  if (_autoState == AutoState::MANUAL)
  {
    _rateOfPenetrationMMpRev = rateOfPenetrationMMpRev;
    _targetSpiralRPS = targetRPM/60.0;
    _targetDepthMM = targetDepthMM + 15.0; //additional 15 mm to account for potential spilling

    if(_heightSensor.startMeasure())
    {
      _autoState = AutoState::WAITING_FOR_HEIGHT;
    }
    else { enterError(); }
    
    return true;
  }
  else
    return false;
}

// Connection checks
bool DrillController::encoderConnected() {return _linearAxis.encoderConnected(); }
bool DrillController::stepperConnected() {return _linearAxis.driverConnected(); }
bool DrillController::spiralMotorConnected() {return _motorDriver.isConnected(); }
bool DrillController::heightSensorConnected() {return _heightSensor.isConnected(); }

// ------------------------------------------------------------------ //
//  Private                                                           //
// ------------------------------------------------------------------ //

void DrillController::enterError()
{
  _linearAxis.stop();
  _motorDriver.setRPM(0);
  _autoState = AutoState::ERROR;
}

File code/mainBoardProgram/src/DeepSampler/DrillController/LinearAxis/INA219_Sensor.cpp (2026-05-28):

#include "INA219_Sensor.h"

// ---------------------------------------------------------------------------
// Konstruktor
// ---------------------------------------------------------------------------
INA219_Sensor::INA219_Sensor(TwoWire &wire, uint8_t address)
    : _wire(&wire),
      _address(address),
      _initialized(false),
      _bvr(RANGE_32V),
      _pga(PGA_8),
      _badc(ADC_12BIT),
      _sadc(ADC_12BIT),
      _rShunt(0.1f),
      _currentLSB(0.0f),
      _powerLSB(0.0f),
      _lastCurrentA(0.0f),
      _lastBusVoltageV(0.0f),
      _lastPowerW(0.0f),
      _measuring(false),
      _dataReady(false)
{
}

// ---------------------------------------------------------------------------
// Inicializace
// ---------------------------------------------------------------------------
bool INA219_Sensor::begin(float rShuntOhm, float maxCurrentA,
                           BusVoltageRange bvr, PGAGain pga,
                           ADCResolution badc, ADCResolution sadc)
{
    if (!isConnected()) {
        return false;
    }

    _bvr  = bvr;
    _pga  = pga;
    _badc = badc;
    _sadc = sadc;

    reset();
    delay(1); // počkat na dokončení resetu

    applyConfiguration();
    setCalibration(rShuntOhm, maxCurrentA);

    _initialized = true;
    return true;
}

void INA219_Sensor::reset() {
    // Bit 15 = RST – softwarový reset, self-clearing
    writeRegister(REG_CONFIG, 0x8000);
}

// ---------------------------------------------------------------------------
// Konfigurace
// ---------------------------------------------------------------------------
void INA219_Sensor::applyConfiguration() {
    // Bit 13: BRNG (bus voltage range)
    // Bity 11-12: PG1, PG0 (PGA gain)
    // Bity 7-10: BADC
    // Bity 3-6:  SADC
    // Bity 0-2:  MODE = 0b111 (shunt + bus, continuous)
    uint16_t config = 0x0000;

    config |= (uint16_t)(_bvr  & 0x01) << 13;
    config |= (uint16_t)(_pga  & 0x03) << 11;
    config |= (uint16_t)(_badc & 0x0F) << 7;
    config |= (uint16_t)(_sadc & 0x0F) << 3;
    config |= 0x07; // MODE: shunt + bus, continuous

    writeRegister(REG_CONFIG, config);
}

void INA219_Sensor::setCalibration(float rShuntOhm, float maxCurrentA) {
    _rShunt = rShuntOhm;

    // Current_LSB = MaxCurrent / 2^15
    _currentLSB = maxCurrentA / 32768.0f;

    // Power_LSB = 20 * Current_LSB
    _powerLSB = 20.0f * _currentLSB;

    // Cal = trunc(0.04096 / (Current_LSB * R_shunt))
    uint16_t cal = (uint16_t)(0.04096f / (_currentLSB * _rShunt));

    writeRegister(REG_CALIBRATION, cal);
}

void INA219_Sensor::setBusVoltageRange(BusVoltageRange bvr) {
    _bvr = bvr;
    applyConfiguration();
}

void INA219_Sensor::setPGAGain(PGAGain pga) {
    _pga = pga;
    applyConfiguration();
}

void INA219_Sensor::setBusADC(ADCResolution res) {
    _badc = res;
    applyConfiguration();
}

void INA219_Sensor::setShuntADC(ADCResolution res) {
    _sadc = res;
    applyConfiguration();
}

// ---------------------------------------------------------------------------
// Jednorázová (blokující) čtení
// ---------------------------------------------------------------------------
float INA219_Sensor::readCurrentA() {
    int16_t raw = (int16_t)readRegister(REG_CURRENT);
    _lastCurrentA = raw * _currentLSB;
    return _lastCurrentA;
}

float INA219_Sensor::readCurrentMA() {
    return readCurrentA() * 1000.0f;
}

float INA219_Sensor::readShuntVoltageMV() {
    int16_t raw = (int16_t)readRegister(REG_SHUNTVOLT);
    // LSB shunt napětí = 10 µV → převod na mV
    return raw * 0.01f;
}

float INA219_Sensor::readBusVoltageV() {
    uint16_t raw = readRegister(REG_BUSVOLT);
    // Bity 15:3 = data, bity 2:0 = příznaky – posun o 3
    // LSB = 4 mV
    _lastBusVoltageV = (float)(raw >> 3) * 0.004f;
    return _lastBusVoltageV;
}

float INA219_Sensor::readPowerW() {
    uint16_t raw = readRegister(REG_POWER);
    _lastPowerW = raw * _powerLSB;
    return _lastPowerW;
}

float INA219_Sensor::readPowerMW() {
    return readPowerW() * 1000.0f;
}

// ---------------------------------------------------------------------------
// Stav a info
// ---------------------------------------------------------------------------
bool INA219_Sensor::isConnected() const {
    _wire->beginTransmission(_address);
    return (_wire->endTransmission() == 0);
}

uint8_t INA219_Sensor::getAddress() const {
    return _address;
}

bool INA219_Sensor::isMathOverflow() {
    uint16_t busReg = readRegister(REG_BUSVOLT);
    return (busReg & 0x01) != 0; // bit 0 = OVF
}

bool INA219_Sensor::isConversionReady() {
    uint16_t busReg = readRegister(REG_BUSVOLT);
    return (busReg & 0x02) != 0; // bit 1 = CNVR
}

float INA219_Sensor::getLastCurrentA()    const { return _lastCurrentA; }
float INA219_Sensor::getLastCurrentMA()   const { return _lastCurrentA * 1000.0f; }
float INA219_Sensor::getLastBusVoltageV() const { return _lastBusVoltageV; }
float INA219_Sensor::getLastPowerW()      const { return _lastPowerW; }
float INA219_Sensor::getCurrentLSB()      const { return _currentLSB; }
float INA219_Sensor::getPowerLSB()        const { return _powerLSB; }
float INA219_Sensor::getRShunt()          const { return _rShunt; }

// ---------------------------------------------------------------------------
// Neblokující průměrované měření
// ---------------------------------------------------------------------------
bool INA219_Sensor::startMeasure() {
    if (!_initialized) return false;
    _lastUpdateMs      = 0;       // vynutí první měření okamžitě
    _measuring         = true;
    _filterInitialized = false;
    return true;
}

bool INA219_Sensor::dataReady() {
    return _filterInitialized;
}

float INA219_Sensor::getAveragedCurrentA() const {
    //Serial0.println(_lastCurrentA);
    //Serial0.println(_filteredCurrentA);
    return _filteredCurrentA;
}

float INA219_Sensor::getAveragedCurrentMA() const {
    return _filteredCurrentA * 1000.0f;
}

void INA219_Sensor::update()
{
    if (!_initialized || !_measuring) return;
   
    uint32_t now = millis();
    if (now - _lastUpdateMs < _intervalMs) return;   // ještě není čas

    if (!isConversionReady()) return;

    _lastUpdateMs = now;

    int16_t raw = (int16_t)readRegister(REG_CURRENT);
    float sample = raw * _currentLSB;

    if (!_filterInitialized) {
        _filteredCurrentA = sample;
        _filterInitialized = true;
    } else {
        _filteredCurrentA += _alpha * (sample - _filteredCurrentA);
    }

    _lastCurrentA = _filteredCurrentA;
}

// ---------------------------------------------------------------------------
// Nízkoúrovňový přístup k registrům
// ---------------------------------------------------------------------------
void INA219_Sensor::writeRegister(uint8_t reg, uint16_t value) {
    _wire->beginTransmission(_address);
    _wire->write(reg);
    _wire->write((uint8_t)(value >> 8));   // MSB první
    _wire->write((uint8_t)(value & 0xFF)); // LSB druhý
    _wire->endTransmission();
}
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

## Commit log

2025-02-13 Add files via upload
    Initial commit of our pcb project
    [drill_pcb.kicad_pcb, drill_pcb.kicad_sch]
2025-02-13 Add files via upload
    test
    [drill_pcb.kicad_sch]
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2025-02-16 fix ERC errors
    [drill_pcb.kicad_sch]
2025-02-17 Add central microcontroller project
    [configuration_flags.h]
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2025-02-18 Rozsireni schématu o rizeni motoru. Ignorovani kicad backupu. Zavedeni kicad projektovych knihoven.
    [drill_pcb.kicad_sch]
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2025-02-19 Library manager update
    [drill_pcb.kicad_sch]
2025-02-19 uprava schématu
    rozsireni gitignore o drill_pcb/fp-info-chache
    [drill_pcb.kicad_sch]
2025-02-22 storage and weighing scheme added
    [drill_pcb.kicad_sch]
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2025-03-13 replaced movingAverage.h with FIR.h replaced motor speed averaging with duty cycle averaging
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2025-03-21 add central microcontroller pcb
    [centrall_microcontroller.kicad_pcb, centrall_microcontroller.kicad_sch, drill_pcb.kicad_pcb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]
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2025-03-25 linear PID fix
2025-03-27 pid update, reset encoders function
2025-03-28 Motor_stucked function fix
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2025-03-31 add linear motor schematic
    [drill_pcb.kicad_sch]
2025-04-03 Setpoint filter rework, added deadzone compensation
2025-04-08 values change
    [centrall_microcontroller.kicad_sch]
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2025-04-16 pcb update
    [drill_pcb.kicad_pcb, drill_pcb.kicad_sch]
2025-04-16 PCB power distribution update
    [drill_pcb.kicad_sch]
2025-04-16 zasobnik ready na 24V
    [drill_pcb.kicad_sch]
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2025-04-23 Schematic divided into subsheets
    [drill_pcb.kicad_pcb, drill_pcb.kicad_sch, linearDriveControl.kicad_sch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]
2025-04-25 added motor heatsink footprint
    [drill_pcb.kicad_pcb]
2025-04-25 added RESET connections into subsheets
    [drill_pcb.kicad_sch, linearDriveControl.kicad_sch, motorControl.kicad_sch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]
2025-04-25 add 8ch logic converter
    [drill_pcb.kicad_sch]
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2025-04-29 Mostly finished PCB v1.0.0 Missing strain gauge control circuit
    [drill_pcb.kicad_pcb, drill_pcb.kicad_sch, linearDriveControl.kicad_sch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]
2025-04-29 update pouzdra konvertoru
    [drill_pcb.kicad_pcb, storageAndWeighing.kicad_sch]
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2025-05-14 PCB update Fixed connector silkscreen. Added H-bridge capacitors.
    [drill_pcb.kicad_pcb, linearDriveControl.kicad_sch, motorControl.kicad_sch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]
2025-05-15 PCB update Stepper drivers moved to make space for RPi USB cable.
    [drill_pcb.kicad_pcb, motorControl.kicad_sch]
2025-05-16 PCB update swapped level shifter board for IC
    [drill_pcb.kicad_pcb, drill_pcb.kicad_sch]
2025-05-18 Longer deadTime, reset pico when unreachable agent
2025-05-19 add libs into the project
    [central_microcontroller.kicad_pcb, central_microcontroller.kicad_sch, centrall_microcontroller.kicad_pcb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]
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2025-05-25 New service to reset pico
2025-05-26 Add init reset, storing height on pico
2025-05-26 Add state to reset pico, storing errors from linear
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2025-08-12 fast PWM no longer experimental
2025-08-12 Got rid of cascade control. Code simplification.
    [drill_pcb.kicad_sch, linearDriveControl.kicad_sch, motorControl.kicad_sch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]
2025-08-12 utery verze 1 - fix smeru motoru
2025-08-13 Speed calculation was broken after PWM changes. Calculation now fixed. Tuned PI controller parameters.
2025-08-13 H-bridge IN pins connected to fast PWM Arduino pins on both schematic and PCB.
    [drill_pcb.kicad_pcb]
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2025-11-18 pcb cleanup
    [drill_pcb.kicad_pcb, drill_pcb.kicad_sch, linearDriveControl.kicad_sch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]
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2026-03-03 corrected caaitor sier on board
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2026-03-06 reroute the adc board and prepare fabrication outputs
    [adc board-B_Cu.gbr, adc board-B_Mask.gbr, adc board-B_Paste.gbr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]
2026-03-07 pcb changes, added ESP library
    [drill_pcb.kicad_pcb, drill_pcb.kicad_sch]
2026-03-11 adc board scaled down
    [adc board.kicad_pcb]
2026-03-11 fix drc errors and recreate grbl files
    [adc board-B_Cu.gbr, adc board-B_Mask.gbr, adc board-B_Paste.gbr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]
2026-03-11 3.3 voltage level to address selection
    [adc board.kicad_pcb, adc board.kicad_sch]
2026-03-11 PCB changes
    [drill_pcb.kicad_sch]
2026-03-11 pridany drivery a ldo (nehotove)
    [drill_pcb.kicad_pcb, drill_pcb.kicad_sch]
2026-03-12 regenerate adc gerber files
    [adc board-B_Cu.gbr, adc board-B_Mask.gbr, adc board-B_Paste.gbr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]
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2026-03-12 Further work on the PCB. Schematic complete AFAIK. Routing in progress.
    [drill_pcb.kicad_pcb, drill_pcb.kicad_sch]
2026-03-12 PCB should be fully complete now. Somebody pls review it :(
    [drill_pcb.kicad_pcb, drill_pcb.kicad_sch]
2026-03-13 Added drill pcb fabrication output
    [drill_pcb-B_Cu.gbr, drill_pcb-B_Mask.gbr, drill_pcb-B_Paste.gbr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]
2026-03-16 Change capacitor sizes and re-export manufacturing files
    [drill_pcb-B_Cu.gbr, drill_pcb-B_Mask.gbr, drill_pcb-B_Paste.gbr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]
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2026-03-24 smaller holes for DCDC stepdown footprint
    [drill_pcb.kicad_pcb]
2026-03-24 finished new fuse holder library. PCB tweaks.
    [drill_pcb.kicad_pcb, drill_pcb.kicad_sch]
2026-03-30 minor code improvements, bug fixes
    [CubeMarsV2.cpp, CubeMarsV2.h, mainBoardProgram.ino]
2026-04-06 Cloned last version of PCB to preserve documentation for already manufactured hardware. New version of PCB includes connector for surface sample weighing, UART0 JST connector, I2C pullup resistors, n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
    [drill_pcb-B_Cu.gbr, drill_pcb-B_Mask.gbr, drill_pcb-B_Paste.gbr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]
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2026-04-15 pcb changes, code changes
    [drill_pcb.kicad_sch]
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2026-04-16 ADC redundant 3/4 pins deleted
    [drill_pcb.kicad_pcb, drill_pcb.kicad_sch]
2026-04-16 solved issue with I2C bus refusing to initialize properly.
    [LinearAxis.cpp, mainBoardProgram.ino]
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2026-04-19 single RST MOSFET added
    [drill_pcb.kicad_pcb, drill_pcb.kicad_sch]
2026-04-20 Schematic changes: - Finalised the feature to turn off power for peripherals using a MOSFET. - Connected the stepper motor current sensor.
    [drill_pcb.kicad_pcb, drill_pcb.kicad_sch]
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2026-04-21 assigned servo pwm pins
    [drill_pcb.kicad_sch]
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2026-04-21 ADC's wired up, layout commented
    [drill_pcb.kicad_pcb, drill_pcb.kicad_sch]
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2026-04-23 Board 1.2 ready; drc errors none
    [drill_pcb.kicad_pcb]
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2026-04-28 adjusted adc reset, not tested
    [ADS122C04_LIB.cpp, mainBoardProgram.ino]
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2026-04-30 AK motor library fixes for communication - added timeout and CRC checksums. Additional feature - 0 erpm now sets 0 duty cycle instead of active breaking
    [CubeMarsV2.cpp, CubeMarsV2.h]
2026-05-01 new reset not tested
    [ADS122C04_LIB.cpp]
2026-05-04 changed capacitor footprint sizes
    [drill_pcb.kicad_pcb, drill_pcb.kicad_sch]
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2026-05-13 Last board checkup before manufacturing. If anything goes wrong, it is Šlímova chyba. Do not edit the project anymore.
    [drill_pcb.kicad_pcb]
2026-05-13 added drill_pcb v2 as a reference for the manufactured board. Further changes to the design are to be made to drill_pcb folder.
    [drill_pcb-B_Cu.gbr, drill_pcb-B_Mask.gbr, drill_pcb-B_Paste.gbr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]
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2026-05-14 Last attempt at manufacturing did not work. Adjusted clearances.
    [drill_pcb-B_Cu.gbr, drill_pcb-B_Mask.gbr, drill_pcb-B_Paste.gbr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]
2026-05-14 renamed folders to get rid of spaces
    [drill_pcb-B_Cu.gbr, drill_pcb-B_Mask.gbr, drill_pcb-B_Paste.gbr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]
2026-05-14 generate gerber files rev2
    [drill_pcb-B_Cu.gbr, drill_pcb-B_Mask.gbr, drill_pcb-B_Paste.gbr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]
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2026-05-20 gitignore and folder name changes
    [drill_pcb-B_Cu.gbr, drill_pcb-B_Mask.gbr, drill_pcb-B_Paste.gbr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]
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2026-05-23 Minor structure changes. Bug fixes. Commented out outdated parts of main.
    [CubeMarsV2.cpp, CubeMarsV2.h, DeepSampleHolder.cpp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]
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2026-05-25 Resolved mosfet misplacement for board v3. Deleted history.
    [drill_pcb-B_Cu.gbr, drill_pcb-B_Mask.gbr, drill_pcb-B_Paste.gbr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]
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2026-05-25 new pcb pin changes and stepperPositioner bug fixis
    [DrillController.cpp, StepperPositioner.cpp]
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2026-05-25 drillController autonomy implementation. Does not work yet. Will test further.
    [DeepSampler.cpp, DrillController.cpp, DrillController.h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]
2026-05-26 gui update, autonomy debug, communication fixes.
    [DrillController.cpp, gui.py, mainBoardProgram.ino]
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2026-05-26 stepperpositioner fix
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2026-05-26 Fix stepper conflict by sharing FastAccelStepper engine
    [CubeMarsV2.cpp, CubeMarsV2.h, DeepSampleHolder.cpp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]
2026-05-26 linear axis speed fix
    [LinearAxis.cpp]
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2026-05-27 storage slot number fix
    [LinearAxis.cpp, LinearAxis.h, StepperPositioner.cpp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]
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2026-05-27 pcb backups resolved???
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2026-05-28 linearAxis remove unused methods and fix library bugs
    [LinearAxis.cpp, LinearAxis.h, StepperPositioner.cpp]
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2026-05-28 fix current sensor filter timing
    [INA219_Sensor.cpp, INA219_Sensor.h]
2026-05-28 integration of current sensor. Not working currently.
    [INA219_Sensor.cpp, RoverComm.cpp]
2026-05-28 current measuring fix
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2026-06-04 ADC reset and Servo labels updated
    [drill_pcb.kicad_pcb, drill_pcb.kicad_sch]
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2026-06-07 ADC kicad labels adjusted
    [adc board.kicad_pcb, adc board.kicad_sch]
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2026-06-10 Surface Sample servo bugfix
    [servo_mg.cpp]
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2026-08-06 two weight calls fixed, log timestamp added
    [ADS122C04_LIB.cpp, DeepSampleHolder.cpp, gui.py]
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2026-08-17 ak motor data rework
    [CubeMarsV2.cpp, CubeMarsV2.h, DeepSampler.cpp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]
2026-08-17 motor data rework debug
    [CubeMarsV2.cpp, CubeMarsV2.h, RoverComm.cpp]
2026-08-17 hotfix failed adc init
    [DeepSampler.cpp, SurfaceSampleHolder.cpp]
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2026-08-17 likely fixed tray rotation. Code improvements.
    [DeepSampleHolder.cpp, DeepSampleHolder.h, DeepSampler.cpp]
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2026-08-19 autonomy finishing touches and fixes
    [DeepSampler.cpp]
2026-08-20 storage stall detection bug fix
    [StepperPositioner.cpp]
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2026-08-20 linear axis and limit switch fix
    [LimitSwitch.cpp, LinearAxis.cpp]
2026-08-21 stepper positioner bugfixes
2026-08-21 tof sensor possible fix
2026-08-21 storing sample from greater height. Various fixes.
    [DeepSampler.cpp, DrillController.cpp]
